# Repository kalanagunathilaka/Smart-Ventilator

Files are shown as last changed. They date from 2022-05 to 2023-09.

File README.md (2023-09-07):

# Smart Ventilator

This project aims to develop a low cost smart ventilator system that requires minimum professional interaction to operate using Atmega32 Microcontroller

**Objectives**

- To detect patient’s blood oxygen levels using the blood oxygen sensor (MAX30102)  and to provide oxygen where necessary.
- To monitor the patient’s vitals using the temperature sensor, pressure sensor, heart rate sensor and LCD display and send an alert message to a medical personnel using the gsm module or sound the speaker when it is necessary.
- To monitor a patient's blood oxygen level and automatically switch off oxygen supply when not needed.
- To be able to manually control all parameters of the air and oxygen flow supplied to the patient.

**System Block Diagram**

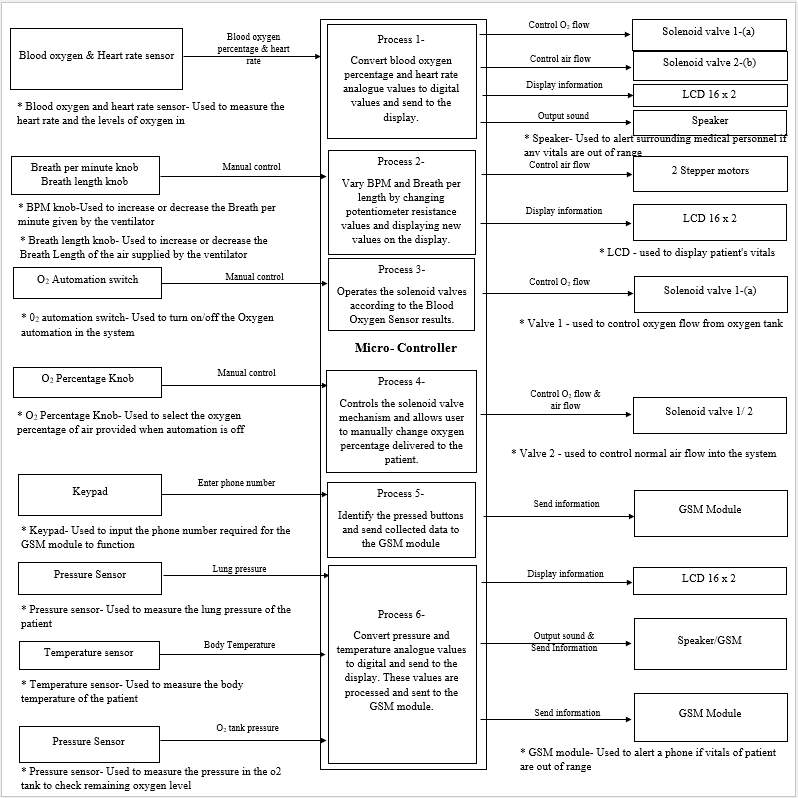
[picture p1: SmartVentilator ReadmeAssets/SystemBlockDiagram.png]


**Schematic of the product**

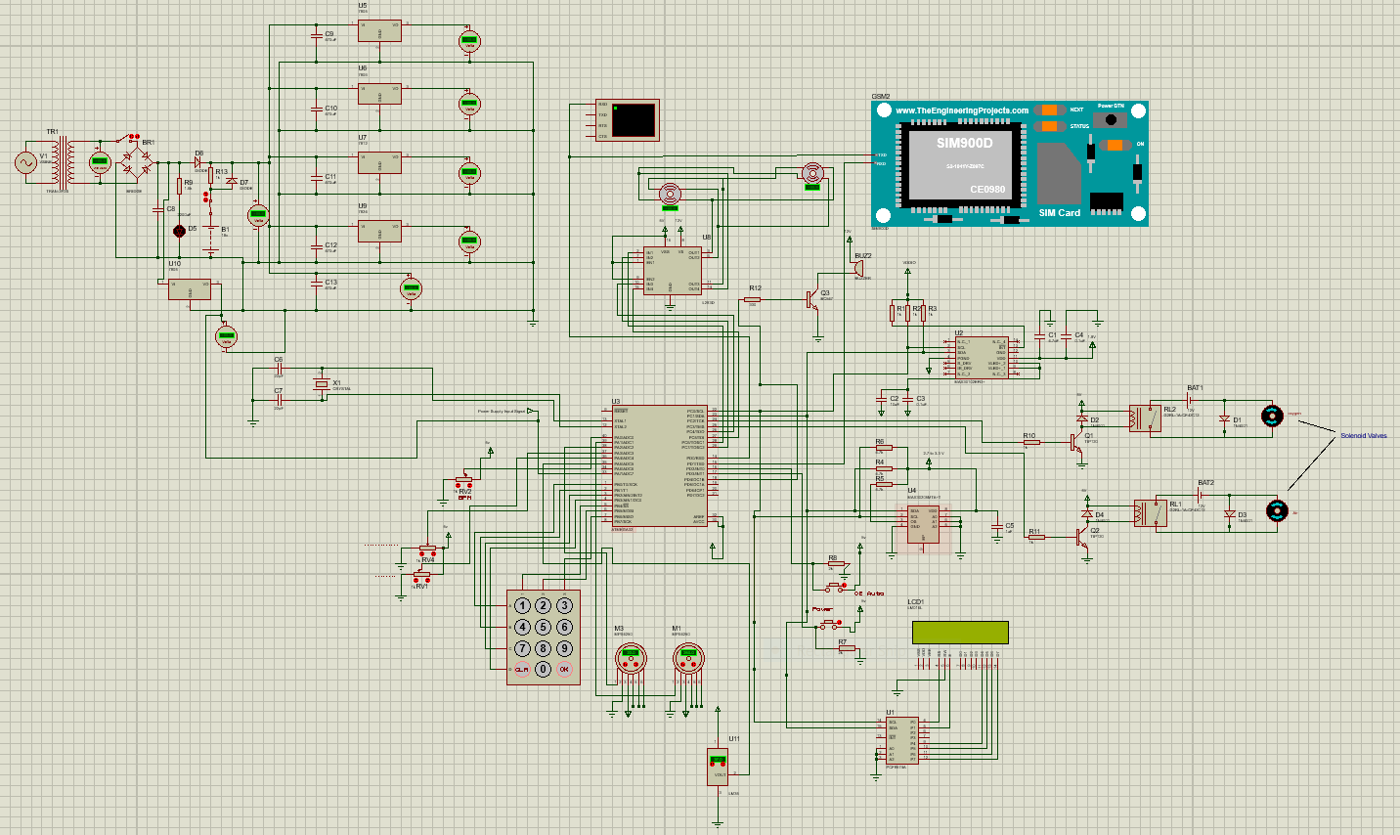
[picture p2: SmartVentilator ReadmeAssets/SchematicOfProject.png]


**3D Design of the System**

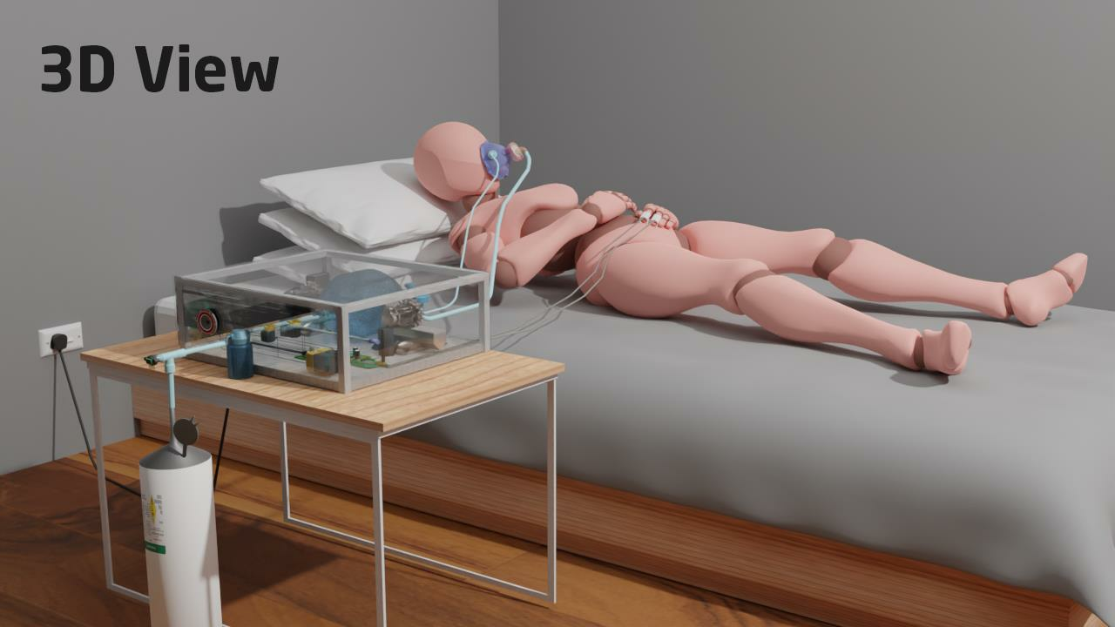
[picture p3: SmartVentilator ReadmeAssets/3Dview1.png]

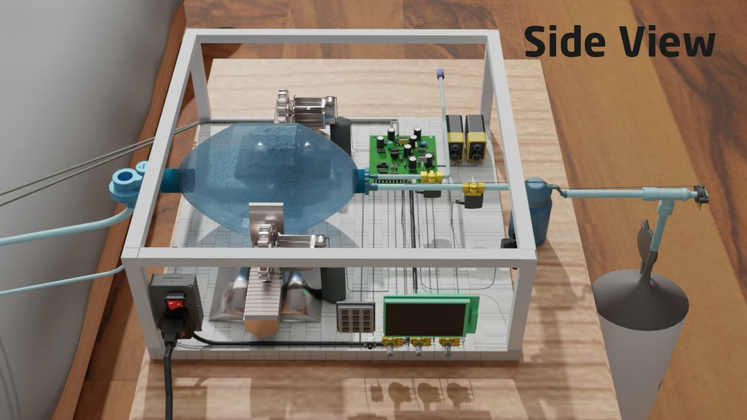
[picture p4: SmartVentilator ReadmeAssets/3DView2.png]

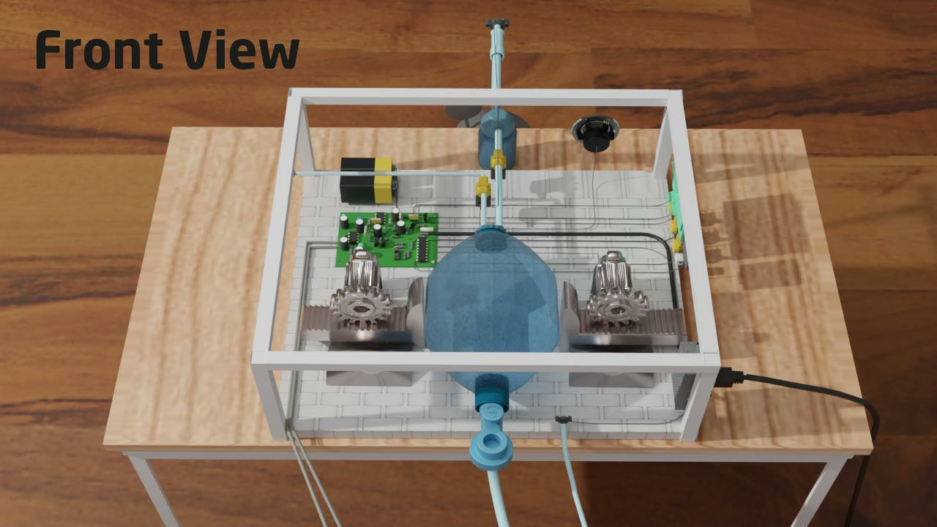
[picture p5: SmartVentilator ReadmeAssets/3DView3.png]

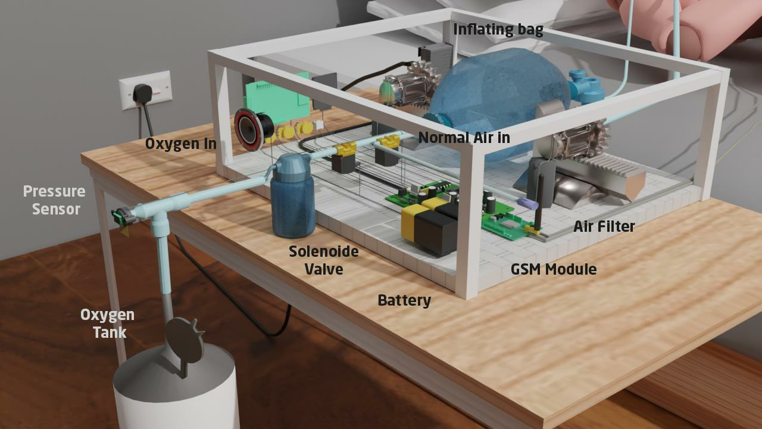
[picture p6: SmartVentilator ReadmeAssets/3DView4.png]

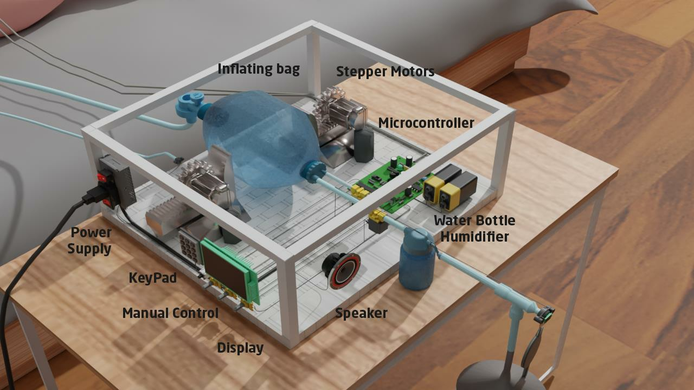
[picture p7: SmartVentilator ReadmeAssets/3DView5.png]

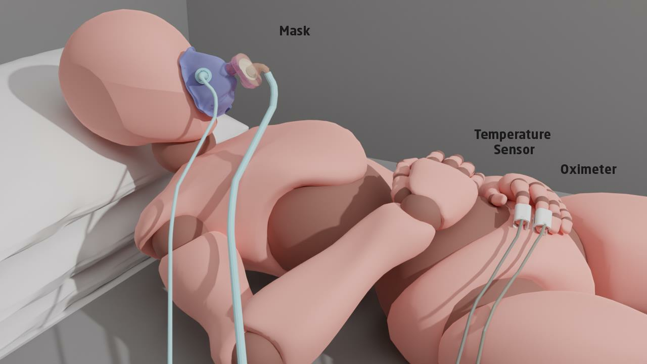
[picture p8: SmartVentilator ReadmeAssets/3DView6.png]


**PCB & 3D View of the Main Board**

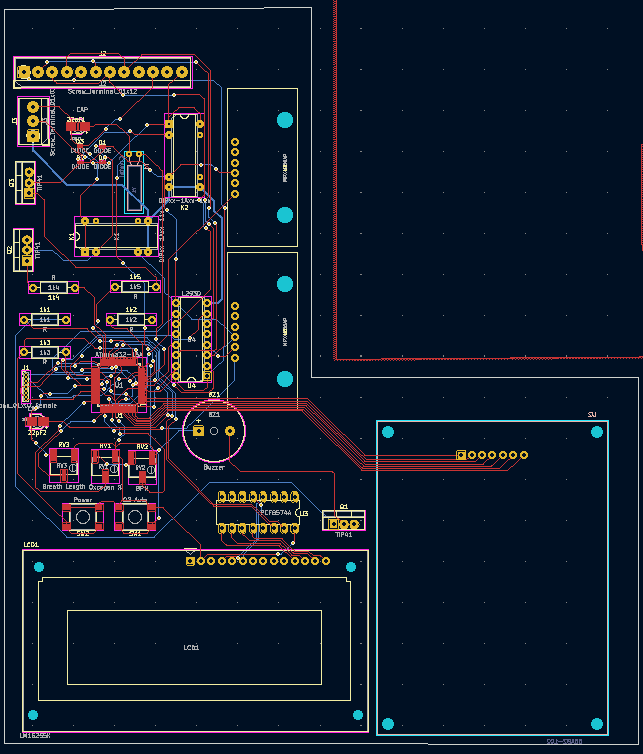
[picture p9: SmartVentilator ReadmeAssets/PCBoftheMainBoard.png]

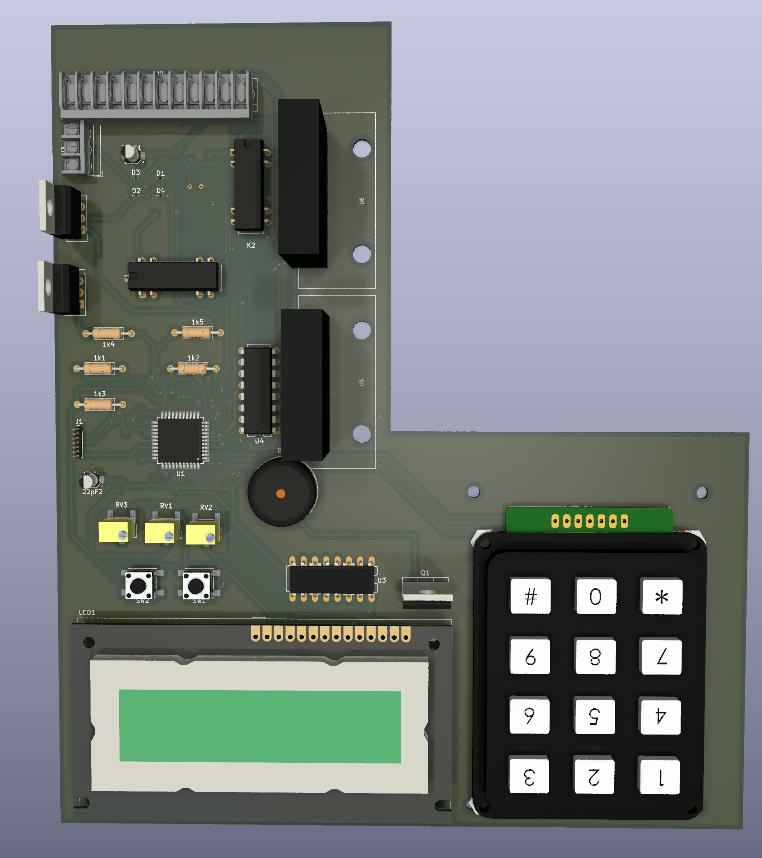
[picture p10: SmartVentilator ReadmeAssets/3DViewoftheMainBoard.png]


**PCB & 3D View of the Heart Rate & SPO2**

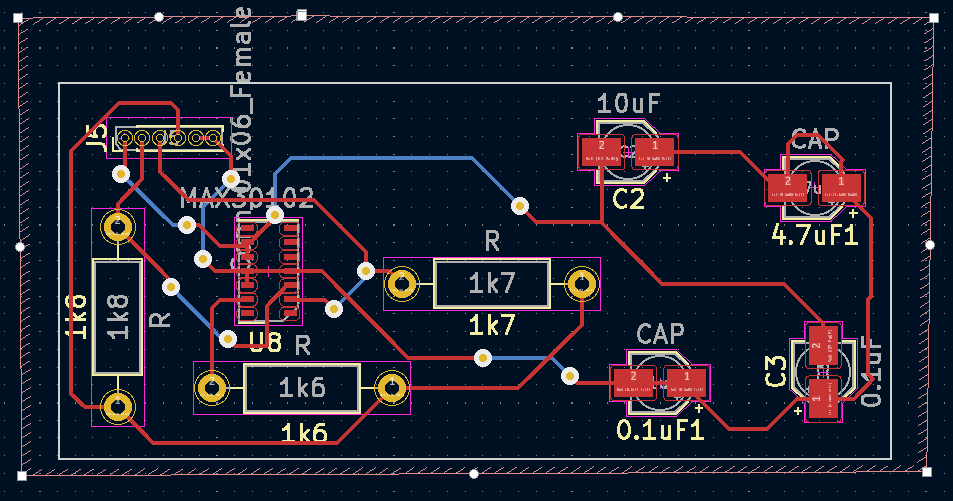
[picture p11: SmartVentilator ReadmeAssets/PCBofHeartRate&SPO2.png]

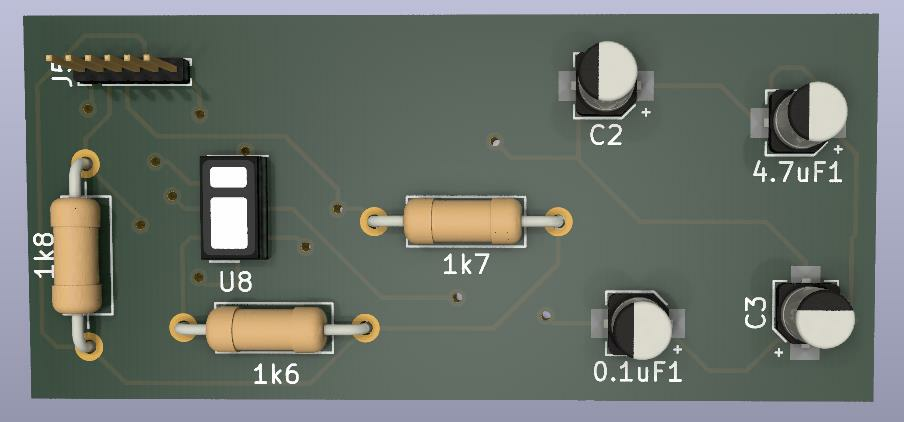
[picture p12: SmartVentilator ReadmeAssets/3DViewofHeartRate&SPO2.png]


**PCB & 3D View of Body Temperature Sensor**

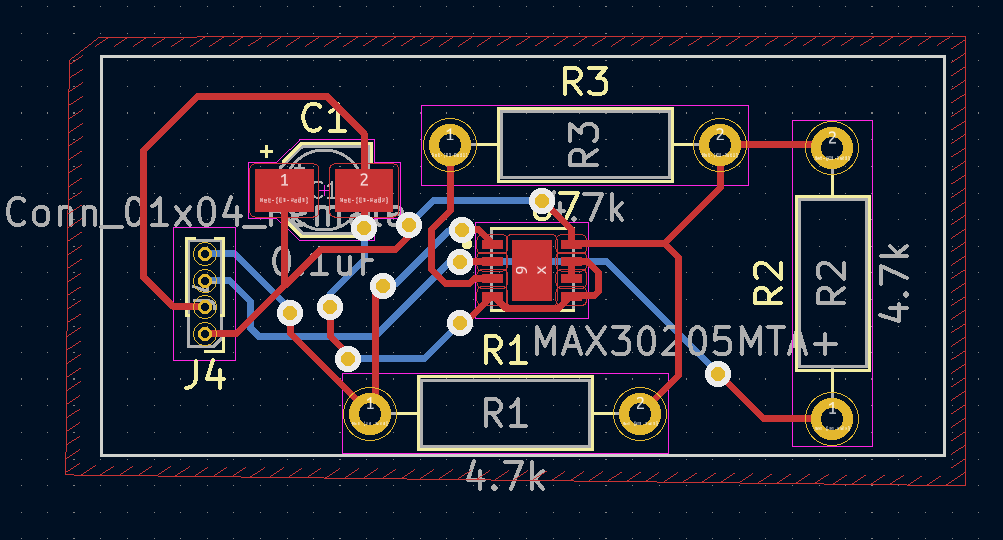
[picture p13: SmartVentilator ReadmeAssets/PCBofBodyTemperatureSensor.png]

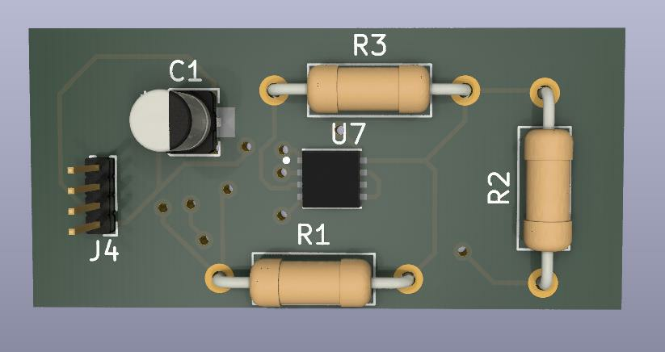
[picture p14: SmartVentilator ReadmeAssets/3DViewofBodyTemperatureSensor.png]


**PCB & 3D View of Power Supply**

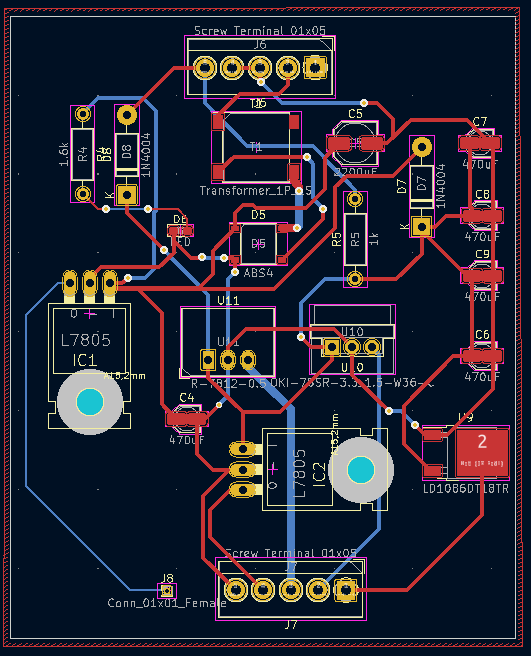
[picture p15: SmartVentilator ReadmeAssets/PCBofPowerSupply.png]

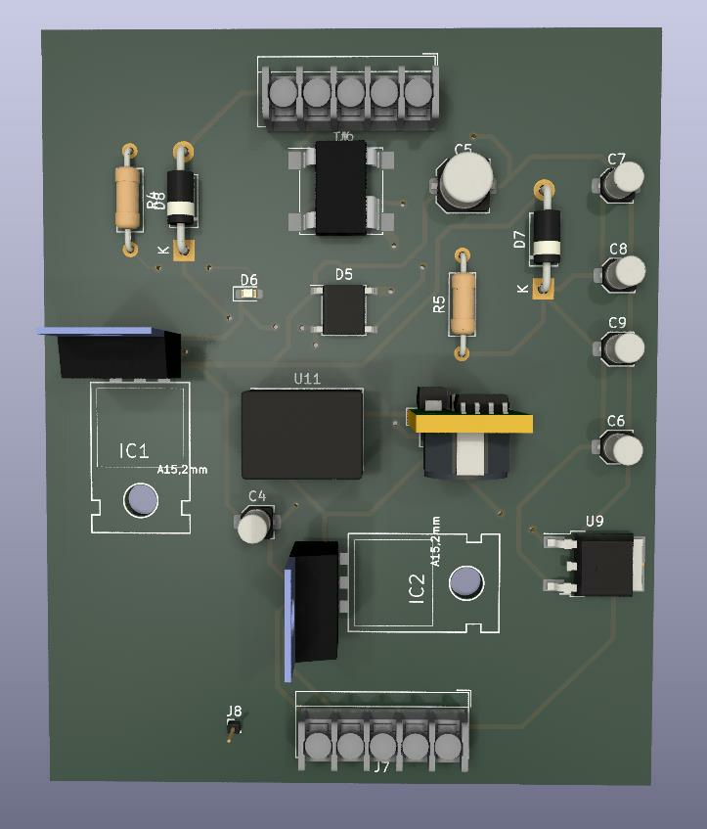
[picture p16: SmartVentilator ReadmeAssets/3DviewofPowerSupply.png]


[**3D Animation**](https://dms.uom.lk/s/HgEqCMnCMRMiKYt)

**Software Used**

- Microchip Studio - Program Microcontroller
- Proteus Design Suite - Design Schematic Diagram
- KiCad EDA - Design PCB
- Blender - Design 3D View
- Adobe After Effects & Premiere Pro - Design 3D Animation

**Contributors**

- [Yesitha Sathsara](https://github.com/yesitha)
- [Shakila Kularathna](https://github.com/shakila2030)
- [Nelaka Gunawardhana](https://github.com/NelakaGunawardhana)
- [Kalana Gunathilaka](https://github.com/KalanaLakshan)
- [Piyumanthi Nisansala](https://github.com/Piyumanthi)

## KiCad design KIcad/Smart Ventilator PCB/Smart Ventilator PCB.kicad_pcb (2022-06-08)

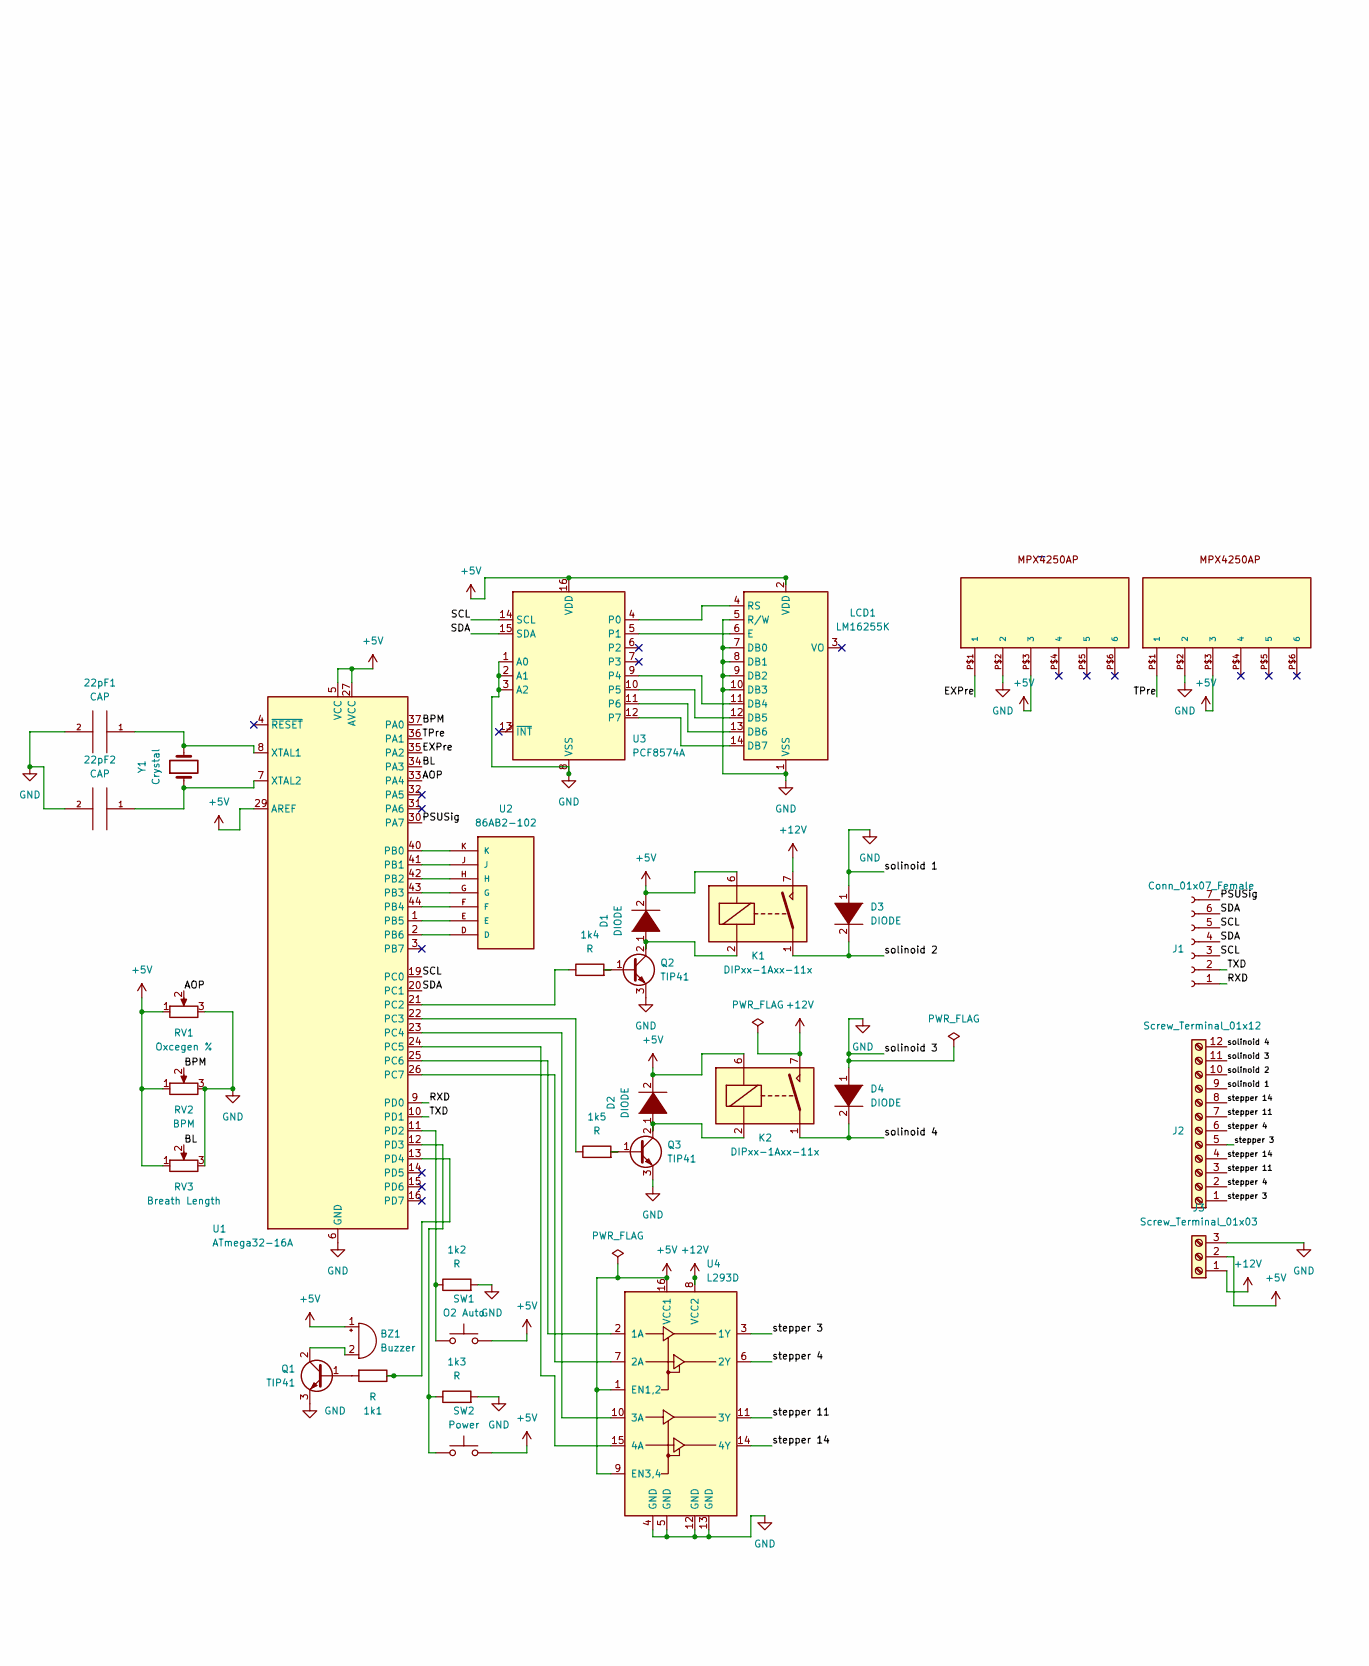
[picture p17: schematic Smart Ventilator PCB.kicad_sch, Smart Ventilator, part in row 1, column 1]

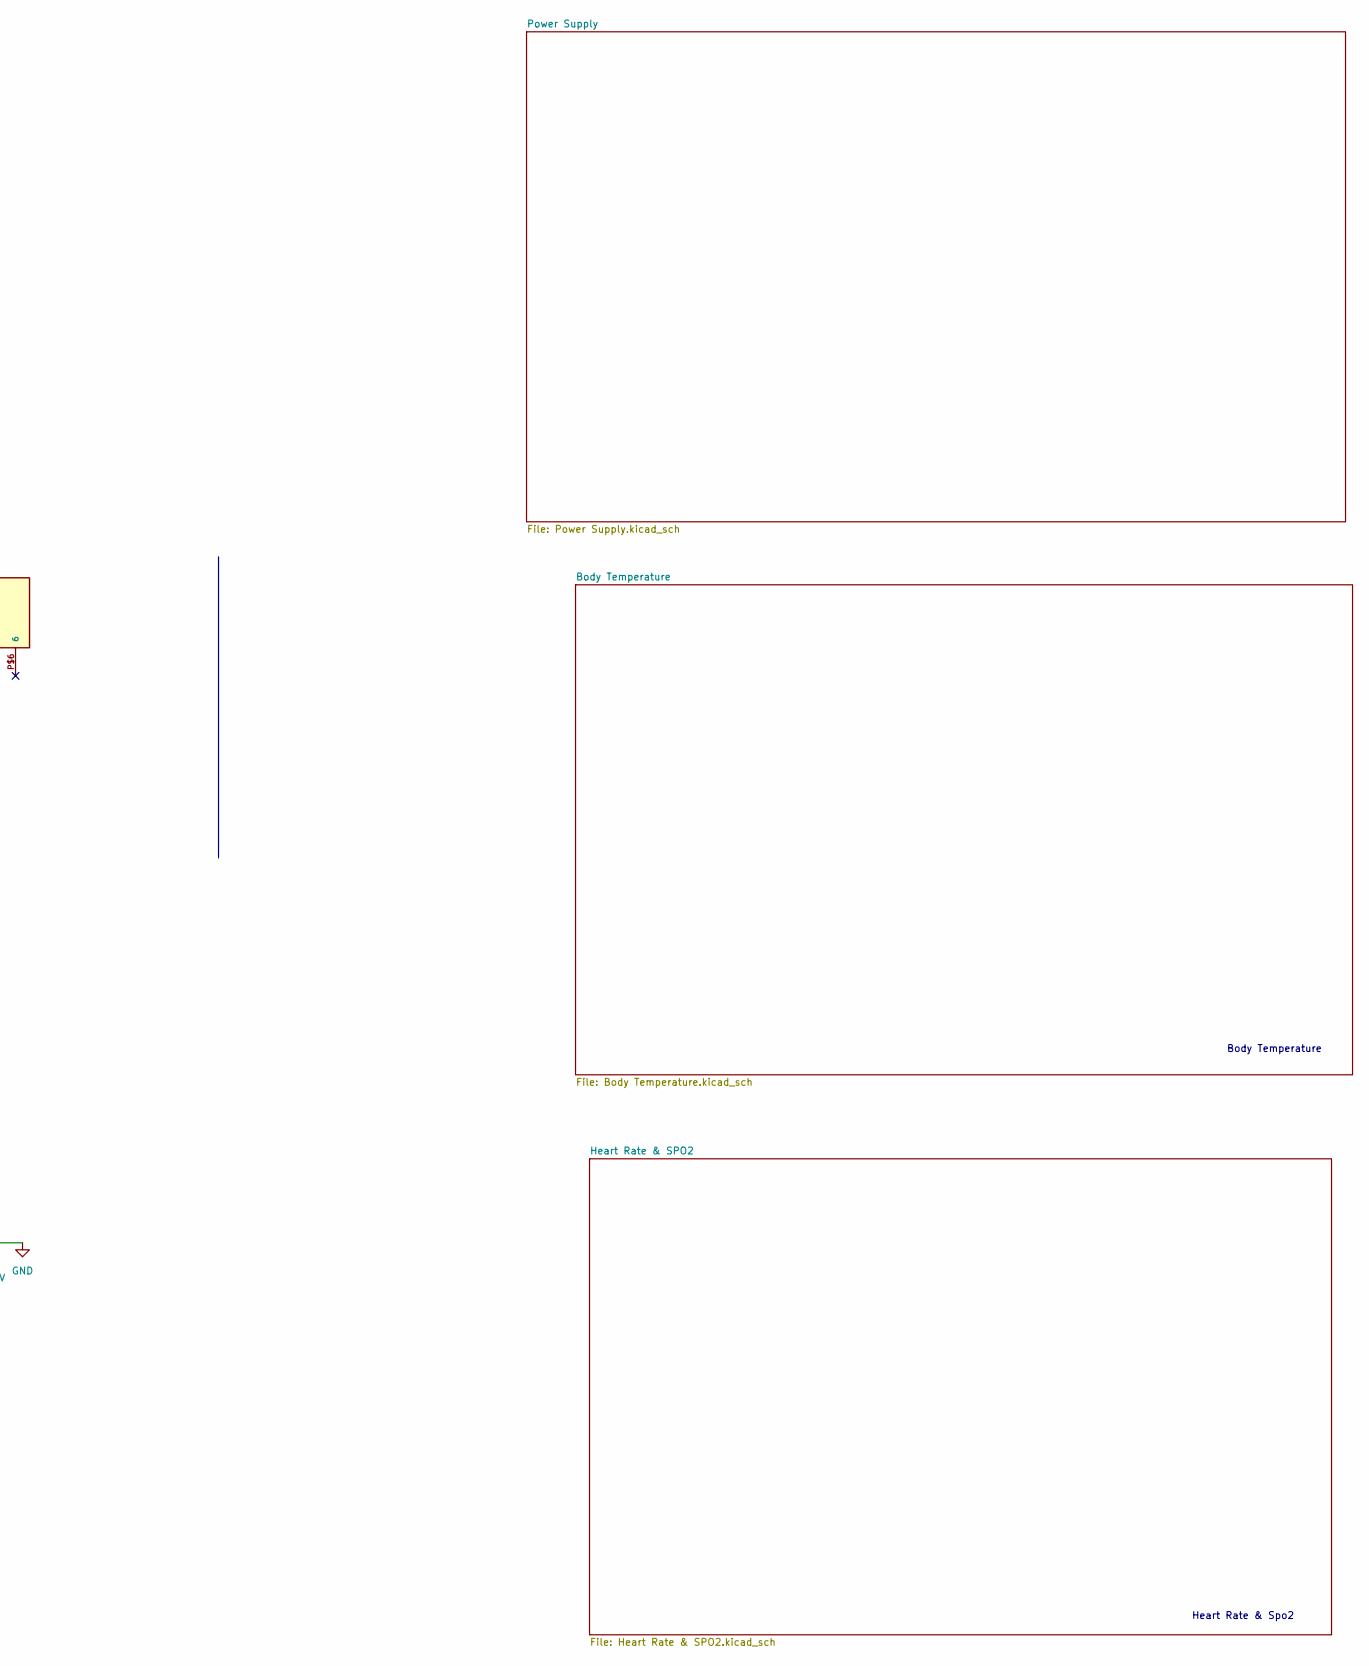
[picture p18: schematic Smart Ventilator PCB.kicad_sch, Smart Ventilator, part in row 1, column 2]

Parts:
1k1, 1k2, 1k3, 1k4, 1k5: R; R_Axial_DIN0207_L6.3mm_D2.5mm_P10.16mm_Horizontal
22pF1, 22pF2: CAP; CP_Elec_3x5.3
BZ1: Buzzer; Buzzer_15x7.5RM7.6
D1, D2, D3, D4: DIODE; D_0201_0603Metric
J1: Conn_01x07_Female; PinHeader_1x07_P1.00mm_Vertical
J2: Screw_Terminal_01x12; TerminalBlock_4Ucon_1x12_P3.50mm_Horizontal
J3: Screw_Terminal_01x03; TerminalBlock_4Ucon_1x03_P3.50mm_Horizontal
K1, K2: DIPxx-1Axx-11x; Relay_StandexMeder_DIP_LowProfile
LCD1: LM16255K; LM16255
Q1, Q2, Q3: TIP41; TO-220-3_Vertical
RV1: Oxcegen %; Potentiometer_Bourns_3269W_Vertical
RV2: BPM; Potentiometer_Bourns_3269W_Vertical
RV3: Breath Length; Potentiometer_Bourns_3269W_Vertical
SW1: O2 Auto; SW_Push_1P1T_NO_6x6mm_H9.5mm
SW2: Power; SW_Push_1P1T_NO_6x6mm_H9.5mm
U1: ATmega32-16A; TQFP-44_10x10mm_P0.8mm
U2: 86AB2-102; KEYPAD_86AB2-102
U3: PCF8574A; DIL16
U4: L293D; DIP-16_W7.62mm
U5, U6: MPX4250AP
Y1: Crystal; Crystal_AT310_D3.0mm_L10.0mm_Horizontal

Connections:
+5V: BZ1.1 (-), D1.2 (A), D2.2 (A), J3.2, K1.6, K2.6, LCD1.2 (VDD), RV1.1, RV2.1, RV3.1, SW1.2, SW2.2, U1.5 (VCC), U1.17 (VCC), U1.27 (AVCC), U1.29 (AREF), U1.38 (VCC), U3.16 (VDD), U4.1 (EN1,2), U4.9 (EN3,4), U4.16 (VCC1), U5.P$3 (3), U6.P$3 (3)
+12V: J3.1, K1.7, K1.8, K2.7, K2.8, U4.8 (VCC2)
/AOP: RV1.2, U1.33 (PA4)
/BL: RV3.2, U1.34 (PA3)
/BPM: RV2.2, U1.37 (PA0)
/EXPre: U1.35 (PA2), U5.P$1 (1)
/PSUSig: J1.7, U1.30 (PA7)
/RXD: J1.1, U1.9 (PD0)
/SCL: J1.3, J1.5, U1.19 (PC0), U3.14 (SCL)
/SDA: J1.4, J1.6, U1.20 (PC1), U3.15 (SDA)
/TPre: U1.36 (PA1), U6.P$1 (1)
/TXD: J1.2, U1.10 (PD1)
/solinoid 2: D3.2 (A), J2.10, K1.1, K1.14
/solinoid 4: D4.2 (A), J2.12, K2.1, K2.14
/stepper 3: J2.1, J2.5, U4.3 (1Y)
/stepper 4: J2.2, J2.6, U4.6 (2Y)
/stepper 11: J2.3, J2.7, U4.11 (3Y)
/stepper 14: J2.4, J2.8, U4.14 (4Y)
GND: 1k2.2, 1k3.2, 22pF1.2, 22pF2.2, D3.1 (K), D4.1 (K), J2.9, J2.11, J3.3, K2.9, K2.13, LCD1.1 (VSS), LCD1.5 (R/W), LCD1.7 (DB0), LCD1.8 (DB1), LCD1.9 (DB2), LCD1.10 (DB3), Q1.3 (E), Q2.3 (E), Q3.3 (E), RV1.3, RV2.3, RV3.3, U1.6 (GND), U1.18 (GND), U1.28 (GND), U1.39 (GND), U3.1 (A0), U3.2 (A1), U3.3 (A2), U3.8 (VSS), U4.4 (GND), U4.5 (GND), U4.12 (GND), U4.13 (GND), U5.P$2 (2), U6.P$2 (2)
unnamed: 1k1.1, U1.13 (PD4)
unnamed: 1k1.2, Q1.1 (B)
unnamed: 1k2.1, SW1.1, U1.11 (PD2)
unnamed: 1k3.1, SW2.1, U1.12 (PD3)
unnamed: 1k4.1, U1.21 (PC2)
unnamed: 1k4.2, Q2.1 (B)
unnamed: 1k5.1, U1.22 (PC3)
unnamed: 1k5.2, Q3.1 (B)
unnamed: 22pF1.1, U1.8 (XTAL1), Y1.2
unnamed: 22pF2.1, U1.7 (XTAL2), Y1.1
unnamed: BZ1.2 (+), Q1.2 (C)
unnamed: D1.1 (K), K1.2, Q2.2 (C)
unnamed: D2.1 (K), K2.2, Q3.2 (C)
unnamed: LCD1.4 (RS), U3.4 (P0)
unnamed: LCD1.6 (E), U3.5 (P1)
unnamed: LCD1.11 (DB4), U3.9 (P4)
unnamed: LCD1.12 (DB5), U3.10 (P5)
unnamed: LCD1.13 (DB6), U3.11 (P6)
unnamed: LCD1.14 (DB7), U3.12 (P7)
unnamed: U1.1 (PB5), U2.E
unnamed: U1.2 (PB6), U2.D
unnamed: U1.23 (PC4), U4.10 (3A)
unnamed: U1.24 (PC5), U4.15 (4A)
unnamed: U1.25 (PC6), U4.2 (1A)
unnamed: U1.26 (PC7), U4.7 (2A)
unnamed: U1.40 (PB0), U2.K
unnamed: U1.41 (PB1), U2.J
unnamed: U1.42 (PB2), U2.H
unnamed: U1.43 (PB3), U2.G
unnamed: U1.44 (PB4), U2.F

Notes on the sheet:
Body Temperature
Heart Rate & Spo2

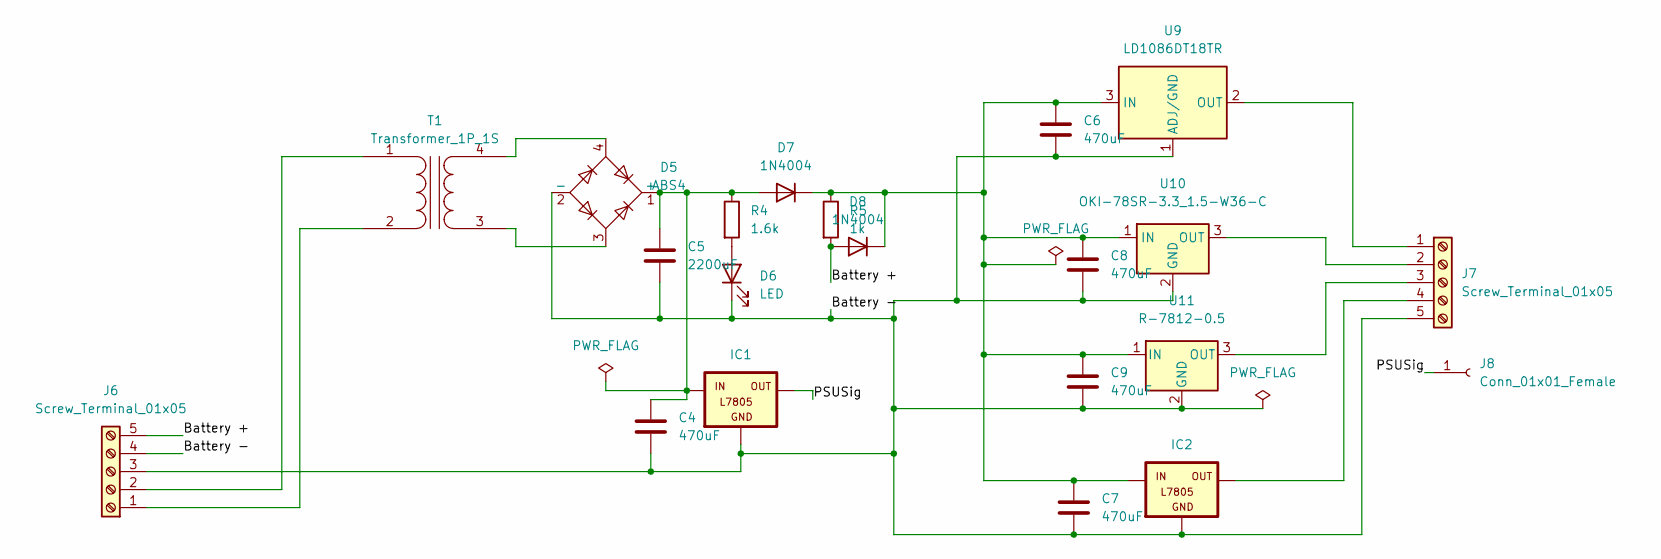
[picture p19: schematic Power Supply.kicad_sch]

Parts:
C4, C6, C7, C8, C9: 470uF; C_Elec_3x5.4
C5: 2200uF; C_Elec_5x5.4
D5: ABS4; Diode_Bridge_Diotec_ABS
D6: LED; LED_0603_1608Metric_Pad1.05x0.95mm_HandSolder
D7, D8: 1N4004; D_DO-41_SOD81_P10.16mm_Horizontal
IC1, IC2: L7805; 78XXL
J6, J7: Screw_Terminal_01x05; TerminalBlock_4Ucon_1x05_P3.50mm_Horizontal
J8: Conn_01x01_Female; PinHeader_1x01_P1.00mm_Vertical
R4: 1.6k; R_Axial_DIN0207_L6.3mm_D2.5mm_P10.16mm_Horizontal
R5: 1k; R_Axial_DIN0207_L6.3mm_D2.5mm_P10.16mm_Horizontal
T1: Transformer_1P_1S; Transformer_Toroid_Horizontal_D9.0mm_Amidon-T30
U9: LD1086DT18TR; TO-252-2
U10: OKI-78SR-3.3_1.5-W36-C; Converter_DCDC_Murata_OKI-78SR_Vertical
U11: R-7812-0.5; Converter_DCDC_RECOM_R-78E-0.5_THT

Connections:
/Power Supply/Battery +: D8.2 (A), J6.5, R5.2
/Power Supply/Battery -: C4.2, C5.2, C6.2, C7.2, C8.2, C9.2, D5.2 (-), D6.1 (K), IC1.GND, IC2.GND, J6.3, J6.4, J7.5, U9.1 (ADJ/GND), U10.2 (GND), U11.2 (GND)
/Power Supply/PSUSig: IC1.OUT, J8.1
unnamed: C4.1, C5.1, D5.1 (+), D7.2 (A), IC1.IN, R4.1
unnamed: C6.1, C7.1, C8.1, C9.1, D7.1 (K), D8.1 (K), IC2.IN, R5.1, U9.3 (IN), U10.1 (IN), U11.1 (IN)
unnamed: D5.3, T1.3 (SA)
unnamed: D5.4, T1.4 (SB)
unnamed: D6.2 (A), R4.2
unnamed: IC2.OUT, J7.4
unnamed: J6.1, T1.2 (AB)
unnamed: J6.2, T1.1 (AA)
unnamed: J7.1, U9.2 (OUT)
unnamed: J7.2, U10.3 (OUT)
unnamed: J7.3, U11.3 (OUT)

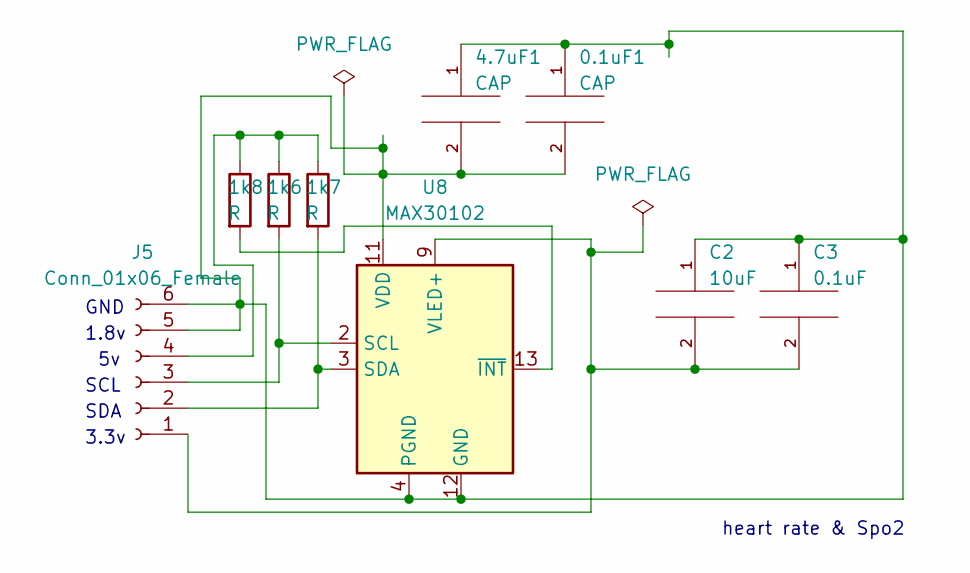
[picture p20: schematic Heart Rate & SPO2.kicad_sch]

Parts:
0.1uF1, 4.7uF1: CAP; CP_Elec_3x5.3
1k6, 1k7, 1k8: R; R_Axial_DIN0207_L6.3mm_D2.5mm_P10.16mm_Horizontal
C2: 10uF; CP_Elec_3x5.3
C3: 0.1uF; CP_Elec_3x5.3
J5: Conn_01x06_Female; PinHeader_1x06_P1.00mm_Vertical
U8: MAX30102; Maxim_OLGA-14_3.3x5.6mm_P0.8mm

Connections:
unnamed: 0.1uF1.1, 0.1uF1.2, 4.7uF1.1, 4.7uF1.2, C2.1, C3.1, J5.5, J5.6, U8.4 (PGND), U8.11 (VDD), U8.12 (GND)
unnamed: 1k6.1, 1k7.1, 1k8.1, J5.4
unnamed: 1k6.2, U8.13 (~INT)
unnamed: 1k7.2, J5.3, U8.2 (SCL)
unnamed: 1k8.2, J5.2, U8.3 (SDA)
unnamed: C2.2, C3.2, J5.1, U8.9 (VLED+), U8.10 (VLED+)

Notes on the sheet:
heart rate & Spo2
GND
SDA
1.8v
SCL
3.3v

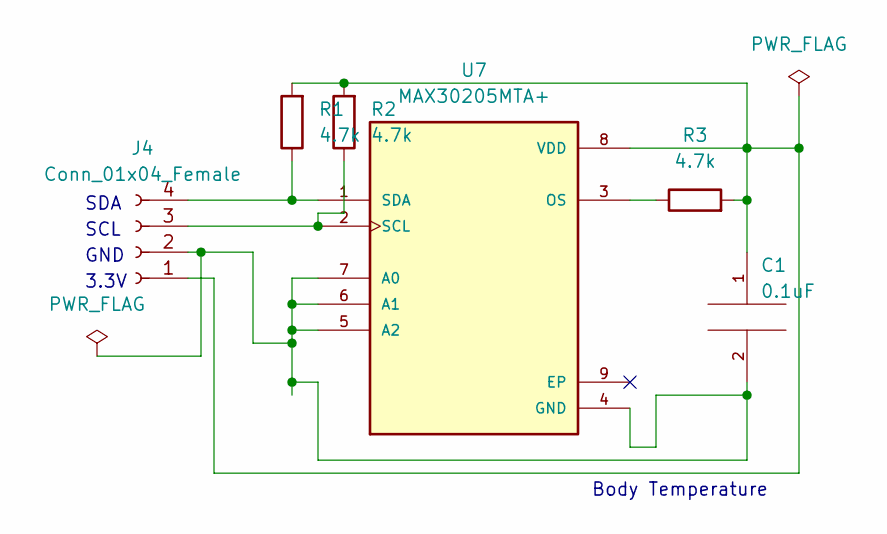
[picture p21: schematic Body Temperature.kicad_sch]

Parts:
C1: 0.1uF; CP_Elec_3x5.3
J4: Conn_01x04_Female; PinHeader_1x04_P1.00mm_Vertical
R1, R2, R3: 4.7k; R_Axial_DIN0207_L6.3mm_D2.5mm_P10.16mm_Horizontal
U7: MAX30205MTA+; SON65P300X300X80-9N

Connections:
unnamed: C1.1, J4.1, R1.2, R2.2, R3.2, U7.8 (VDD)
unnamed: C1.2, J4.2, U7.4 (GND), U7.5 (A2), U7.6 (A1), U7.7 (A0)
unnamed: J4.3, R2.1, U7.2 (SCL)
unnamed: J4.4, R1.1, U7.1 (SDA)
unnamed: R3.1, U7.3 (OS)

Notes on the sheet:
3.3V
SDA
SCL
Body Temperature
GND

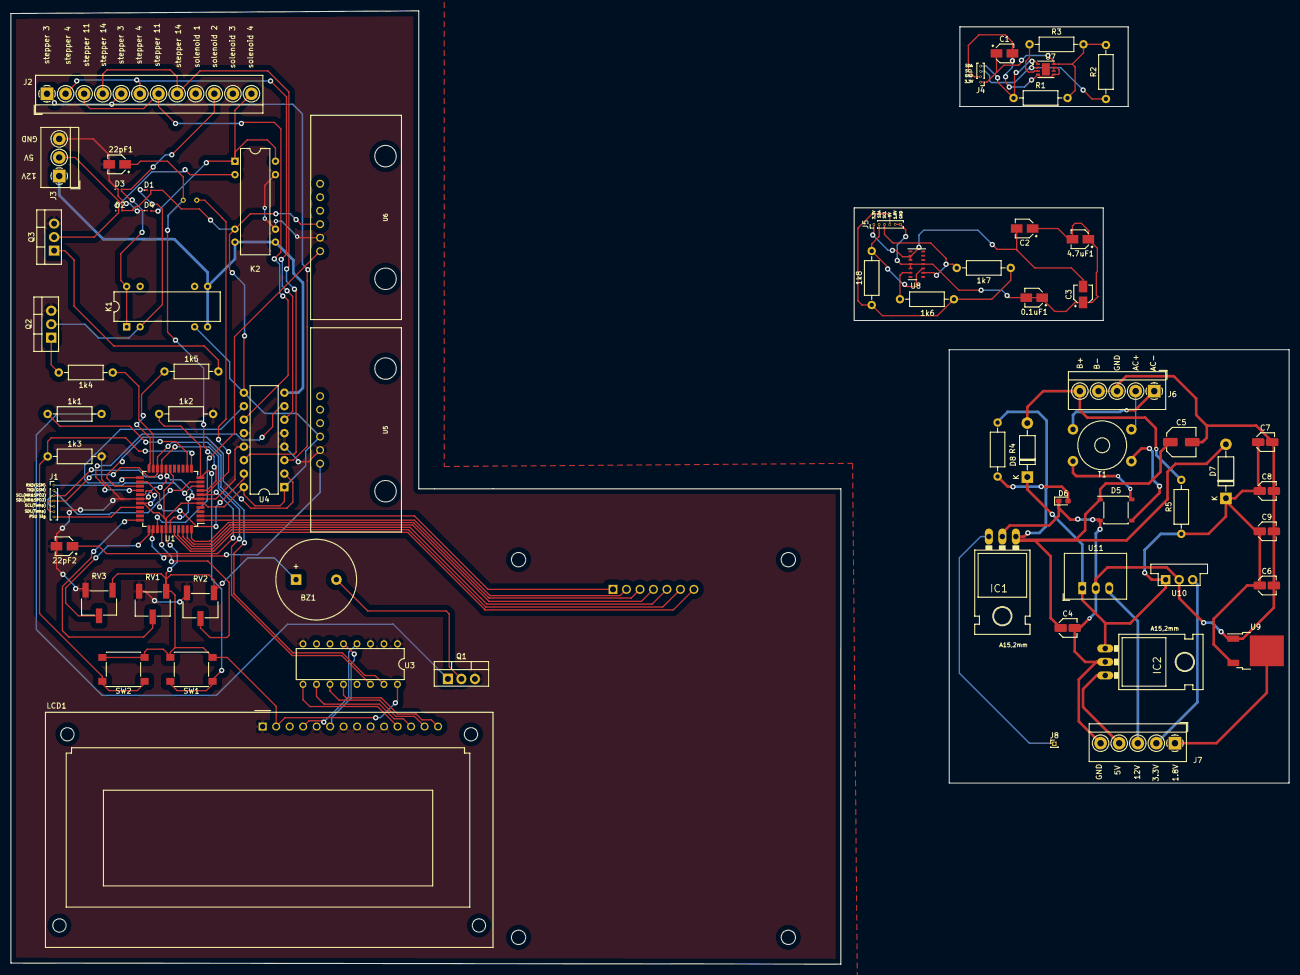
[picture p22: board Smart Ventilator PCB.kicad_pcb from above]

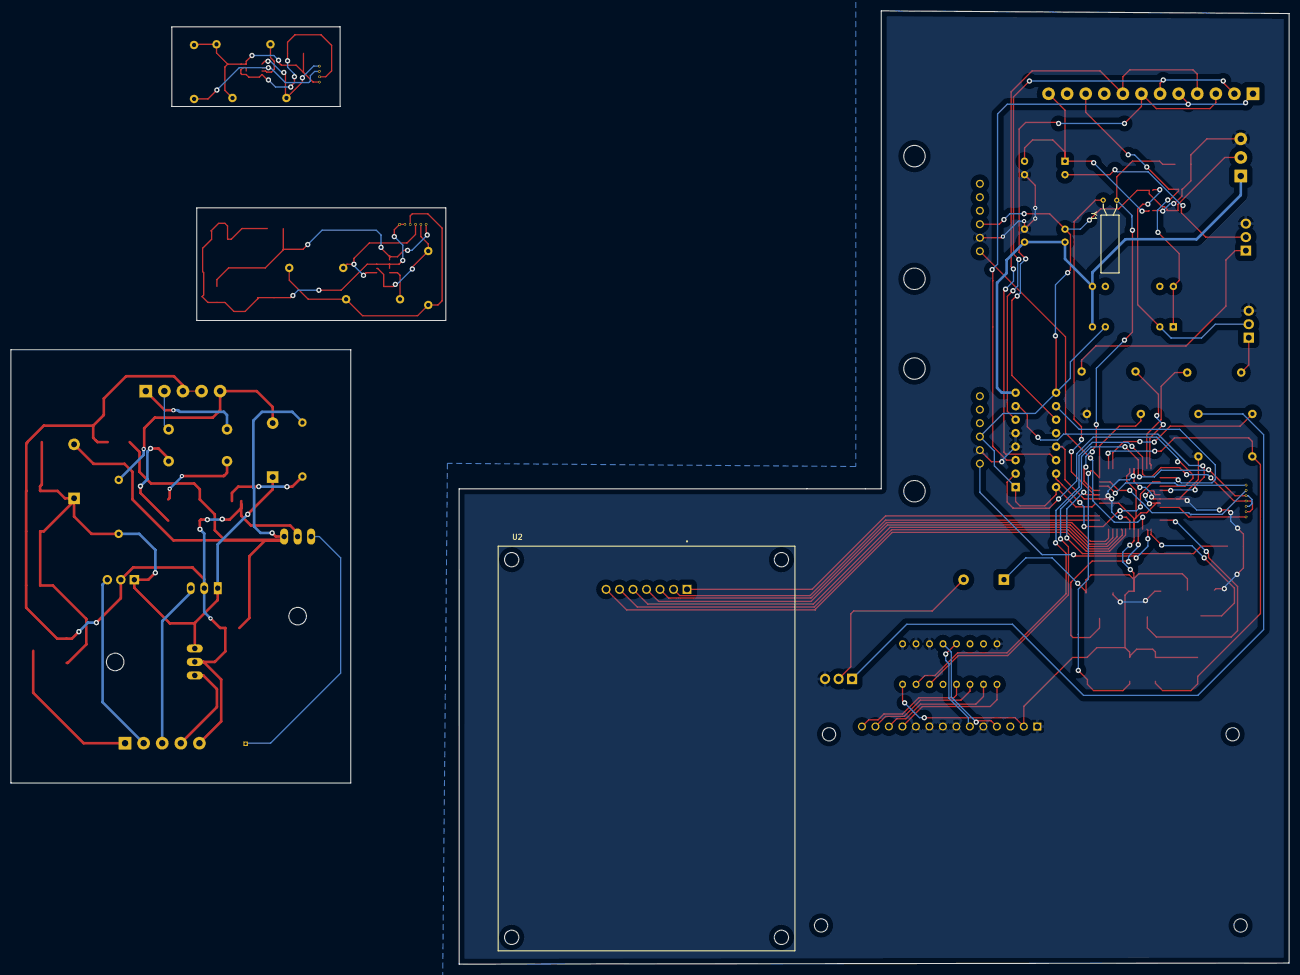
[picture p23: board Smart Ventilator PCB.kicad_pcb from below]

Board: 2 copper layers, 240.7 x 179.5 mm, 69 parts (2 on the bottom side), 74 nets.

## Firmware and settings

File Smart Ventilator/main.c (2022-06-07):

/*
 * Smart Ventilator.c
 *
 * Created: 11/27/2021 1:26:16 PM
 * Author : Yesitha Sathsara
 */
#define F_CPU 8000000UL
#include <avr/io.h>
#include <stdbool.h>
#include <math.h>
#include <util/delay.h>
#include <stdio.h>
#include <string.h>
#include <stdlib.h>
#include <millis.h>
#include <avr/interrupt.h>
#include "lcd.h"
#include "i2c.h"
#include "keypad.h"
#include "string.h"
#include "GSM.h"
#include "solenoidValves.h"
#include "stepper motor.h"
#include "potentiometer.h"
#include "MPX4250 Pressure Sensor.h"
#include "LM35 Temperature Sensor.h"

bool checkStatus();
int oxygenTankPercentage();
void notifyGSM(const char *string, int percentage);
void notifyDisplay(const char *string);
void delay_ms(double ms);
bool automationOn();
void getParametersFromKnobs();
bool checkPatientTemp();
int PatientTemp();
int checkBloodOxygenLevel();
void startAirSupply();
void controlOxygenPercentage(int bloodOxygenLevel);
void notifySpeaker();
bool turnOn();
void startStepperMotor(int breathPerMin, int BreathLength);
void startOxygenAndAirSupply(int percentage);
void controlSolenoidValve(double oxygenPercentage, int breathPerMin);
void rotateFullBackward(int breathPerMin);
void rotateFullForward(int breathPerMin);
double getOxygenTankPressure();
void openSolenoidValves(double air, double oxygen);
void GSMConnect();
void sendSMS(char no[11], const char *string);
bool checkPower();
int checkPatientExpPresure();

const char *concatS(const char *string, char sPercentage[4]);
char *boolstring(_Bool b);
int Average_Blood_Oxygen_level = 94;
int Average_Breath_length = 50;
int Average_Breath_Per_Min = 12;
int Oxygen_percentage = 90;
char Mobile_no[11];

unsigned char x;
bool power = true;
bool OxygenAutomation = true;
int Set_Heart_Rate();

int rBPM;
int rHR;
int rBL;
int rOP;
int i;
int caseADC = 1;
char String[5];
int value;
int powerfailure;
unsigned long case_num2;
unsigned long prev_millis2;
unsigned long need_millis2;

int main(void)
{

    DDRC = DDRC | (1 << 2); // solenoid valve
    DDRC = DDRC | (1 << 3); // solenoid valve
    DDRC = DDRC | (1 << 4); // stepper motor
    DDRC = DDRC | (1 << 5); // stepper motor
    DDRC = DDRC | (1 << 6); // stepper motor
    DDRC = DDRC | (1 << 7); // stepper motor

    DDRB = 0x0F;            // 0,1,3,2--->1   4,5,6,7-->0 for keypad
    DDRD = DDRD | (0 << 2); // PD2 as Oxygen Automation
    DDRD = DDRD | (0 << 3); // PD3 as input for power on
    DDRD = DDRD | (1 << 4); // Speaker
    DDRA = DDRA | (0 << 7); // PA7 as input for power supply

    MCUCR |= 1 << ISC01; // interrupt fire on falling edge in INT0
    MCUCR |= 1 << ISC11; // interrupt fire on falling edge in INT1

    //
    GICR |= 1 << INT0; // Enable the external interrupt source in general interrupt control register
    GICR |= 1 << INT1; // Enable the external interrupt source in general interrupt control register
	
    init_millis(8000000UL);
    sei();
    ADC_Init();
    i2c_init();
    i2c_start();
    i2c_write(0x70);
    lcd_init();
	
	
    lcd_cmd(0x80);
    lcd_msg("Enter Phone");
    _delay_ms(30);
    lcd_cmd(0xC0);
    _delay_ms(10);
    lcd_msg("Number");
    _delay_ms(30);
    lcd_cmd(0x01);
    _delay_ms(100);
    lcd_cmd(0x80);

initialPoint:
    lcd_cmd(0x01);

    PORTB = 0xF0;
    int f = 0;
    do
    {
        x = Keypad();
        Mobile_no[f]=x;
         
        if (((PINB & (1 << PINB4)) == 0) || ((PINB & (1 << PINB5)) == 0) || ((PINB & (1 << PINB6)) == 0))
        {
            f++;
        }
        lcd_msg(x);
        _delay_ms(70);

        if ((PINB & (1 << PINB4)) == 0) // clr button
        {
            goto initialPoint;
        }
        if ((PINB & (1 << PINB6)) == 0) // ok button
        {
            break;
        }

    } while (PINB != 0xF0);
   
    lcd_cmd(0x01);
	lcd_cmd(0x80);
    lcd_msg("Number");
    lcd_cmd(0xc0);
    lcd_msg("Registered");
    _delay_ms(100);
    lcd_cmd(0x01);
	

    USART_Init(9600);
    _delay_ms(1000);
    GSMConnect();
    

    while (1)
    {
		switch (caseADC)
		{
			case 1:
			{
				ADC_Init();
				value = ADC_Read(3);
				rBL = ((value * 500) / 1024) + 250; // BL range vary from 250 to 750
				caseADC++;
				break;
				
			}
			case 2:
			{
				ADC_Init();
				value = ADC_Read(0);
				rBPM = ((value * 14) / 1024) + 10; // BPM range vary from 10 to 24
				caseADC=1;
				break;
			}
			
		}
		
		if(prev_millis2==NULL){
			
			prev_millis2=millis();
			need_millis2=500+prev_millis2;
			case_num2=1;
			     char Spercentage[4];
			     lcd_cmd(0x01);
				 lcd_cmd(0x80);
				 itoa(checkBloodOxygenLevel(), Spercentage, 10);
				 lcd_msg(concatS("PBO2L-", Spercentage));
				 itoa(Set_Heart_Rate(), Spercentage, 10);
				 lcd_msg(concatS("  HR-", Spercentage));
				 lcd_cmd(0xc0);
				 itoa(PatientTemp(), Spercentage, 10);
				 lcd_msg(concatS("Temp-",Spercentage));
				 itoa(checkPatientExpPresure(), Spercentage, 10);
				 lcd_msg(concatS(" ExpP-", Spercentage));
			case_num2++;
			}else if(need_millis1<millis()){
			
			switch(case_num2){
				
				case 2:{
					lcd_cmd(0x01);
					lcd_cmd(0x80);
					char Spercentage1[4];
					itoa(rBPM, Spercentage1, 10);
					lcd_msg(concatS("BPM-", Spercentage1));
					itoa(rBL, Spercentage1, 10);
					lcd_msg(concatS("   BL-", Spercentage1));
					lcd_cmd(0xc0);
					itoa(oxygenTankPercentage(), Spercentage1, 10);
					lcd_msg(concatS("O2TP-", Spercentage1));
					itoa(Oxygen_percentage, Spercentage1, 10);
					lcd_msg(concatS(" AO2P-", Spercentage1));
					case_num2++;
					need_millis2=need_millis2+500;
					break;
				} 
				
				default:{case_num2=NULL;
					prev_millis2=NULL;
				}
			}
		}
		
		
		
		
		
		
		
       
       

        

        if (checkStatus())
        {
            if (automationOn())
            {
                if (checkPatientTemp())
                {

                    if (checkBloodOxygenLevel() < Average_Blood_Oxygen_level)
                    {
                        startOxygenAndAirSupply(Oxygen_percentage);
                    }
                    else
                    {
                        startAirSupply();
                    }
                }
            }
            else
            {
                checkPatientTemp();
                getParametersFromKnobs(); // update o2 percentage manually
                controlSolenoidValve(Oxygen_percentage, rBPM);
                startStepperMotor(rBPM, rBL);
            }
        }
        else
        {
            return 0;
        }
    }
}
ISR(INT0_vect)
{ // External interrupt

    OxygenAutomation = !OxygenAutomation;

    if (OxygenAutomation)
    {
        lcd_cmd(0x01);
        lcd_msg("O2 Auto On");
    }
    else
    {
        lcd_cmd(0x01);
        lcd_msg("O2 Auto Off");
    }
    _delay_ms(50);
    lcd_cmd(0x01);
}
ISR(INT1_vect)
{ // External interrupt
    power = !power;
    if (power)
    {
        lcd_cmd(0x01);
        lcd_msg("Power On");
    }
    else
    {
        lcd_cmd(0x01);
        lcd_msg("Power Off");
    }
    _delay_ms(50);
    lcd_cmd(0x01);
}

void startOxygenAndAirSupply(int percentage)
{
    controlOxygenPercentage(checkBloodOxygenLevel());
    controlSolenoidValve(Oxygen_percentage, rBPM);
    startStepperMotor(rBPM, rBL);
}
void controlOxygenPercentage(int bloodOxygenLevel)
{
    if (bloodOxygenLevel < 40)
    {
        Oxygen_percentage = 90;
    }
    else if (bloodOxygenLevel < 70)
    {
        Oxygen_percentage = 70;
    }
    else if (bloodOxygenLevel < 90)
    {
        Oxygen_percentage = 60;
    }
    else if (bloodOxygenLevel < 94)
    {
        Oxygen_percentage = 40;
    }
    // update variable Oxygen Percentage According to Blood Oxygen Level
}

void controlSolenoidValve(double oxygenPercentage, int breathPerMin)
{
    double inflationTime = 30.0000 / breathPerMin;
    double tAir;    // Air Solenoid Valve Time
    double tOxygen; // Oxygen Solenoid Valve Time
    double constValue;
    double Pressure = 101325;
    double airDensity = 1.225;
    double OxygenDensity = 1.355;

    constValue = (0.79 * (1.266 * oxygenPercentage - 26.67) / (100 - oxygenPercentage)) * sqrt(Pressure * OxygenDensity / getOxygenTankPressure() / airDensity);
    if (constValue > 1)
    {
        tOxygen = inflationTime;
        tAir = tOxygen / constValue;
        openSolenoidValves(tAir, tOxygen); // values in s
    }
    else
    {
        tAir = inflationTime;
        tOxygen = tAir * constValue;
        openSolenoidValves(tAir, tOxygen); // values in s
    }
}

double getOxygenTankPressure()
{
    float kilopascal = get_pressure(1); 
	return kilopascal*1000; // return Oxygen tank pressure in pascal
}

void startAirSupply()
{
    startStepperMotor(rBPM, rBL);
    controlSolenoidValve(0, rBPM);
}
int checkBloodOxygenLevel()
{

    return 39; // return Blood Oxygen Level
}

int PatientTemp()
{
	float temp;
	temp= get_Temperature();
    return temp; // return temperature value
}

void notifySpeaker()
{
    DDRD = DDRD | (1 << 4);
}

bool checkPatientTemp()
{
    if (PatientTemp() > 37.2 || PatientTemp() < 36.1)
    {
        notifyGSM("Temperature Not Normal-", PatientTemp());
        char Spercentage[4];
        itoa(PatientTemp(), Spercentage, 10); // convert int to string
        notifyDisplay(concatS("Abnormal Temp-", Spercentage));
        notifySpeaker();
        return 0;
    }
    else
    {
        return 1;
    }
    // if normal return 1 else notify speaker and gsm
}

void getParametersFromKnobs()
{
 
	 ADC_Init();
	 value = ADC_Read(4);
	 rOP = (100 * value) / 1024; // OP range vary from 0 to 100
	 Oxygen_percentage = rOP;
    // get values and update  Breath per min,Oxygen Percentage,Breath Length
}

bool automationOn()
{
    return OxygenAutomation; // Check Automation On/Off
}

bool turnOn()
{
    return power; // return 1 if power on switched pressed else return 0
}

bool checkStatus()
{
    if (turnOn())
    {
        if (oxygenTankPercentage() < 10)
        {
            notifyGSM("Oxygen Tank Percentage : ", oxygenTankPercentage());
            char Spercentage[4];
            itoa(oxygenTankPercentage(), Spercentage, 10); // convert int to string
            notifyDisplay(concatS("OxyTank % ", Spercentage));
        }
        if (!checkPower())
        {
            if (powerfailure == NULL)
            {
                lcd_msg("POWER FAILURE");
                lcd_cmd(0x01);
                powerfailure = 1;
            }
            notifySpeaker();
        }
        else
        {
            powerfailure = NULL;
            DDRD = DDRD | (0 << 4);
        }
        return 1;
    }
    else
    {
        return 0;
    }
}

void notifyDisplay(const char *string)
{
    lcd_msg(string);
    lcd_cmd(0x01);
}

bool checkPower()
{
    if ((PINA & (1 << PINA7)) == (1 << PINA7))
    {
        return 1; // pin is high
    }
    else
    {
        return 0; // pin is low
    }
}

void notifyGSM(const char *string, int percentage)
{
    char Spercentage[4];
    itoa(percentage, Spercentage, 10); // convert int to string

    sendSMS(Mobile_no, concatS(string, Spercentage));
}
const char *concatS(const char *string, char sPercentage[4])
{
    char *result = malloc(strlen(string) + strlen(sPercentage) + 1);
    strcpy(result, string);
    strcat(result, sPercentage);
    return result;
}

int oxygenTankPercentage()
{
	float x;
	int y;
	x=getOxygenTankPressure();
	y= (100-((300000-x)/3000));
    return y;
}
int checkPatientExpPresure()
{
	float kilopascal = get_pressure(2);
	return kilopascal; // return patient expiration pressure in kilopascal
}

int Set_Heart_Rate()
{
	return 80;
}

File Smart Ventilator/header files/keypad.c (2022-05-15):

/*
 * GccApplication2.c
 *
 * Created: 5/12/2022 11:27:58 PM
 * Author : Piyumanthi
 */ 
#define F_CPU 16000000UL
#include <avr/io.h>
#include<util/delay.h>
#include "LCD16x2_4bit.h"

char Keypad()
{
	
	PORTB=0b1111110;         // make first row 0
	if((PINB &(1<<PINB4))==0)
	{
		_delay_ms(3);
		return'1';
	}

	else if((PINB&(1<<PINB5))==0)
	{
		_delay_ms(3);
		return'2';
	}
	else if((PINB&(1<<PINB6))==0)
	{
		_delay_ms(3);
		return'3';
	}
	

	PORTB=0b1111101;   // make second row 0
	if((PINB &(1<<PINB4))==0)
	{
		_delay_ms(3);
		return'4';
	}
	else if((PINB&(1<<PINB5))==0)
	{
		_delay_ms(3);
		return'5';
	}
	else if((PINB&(1<<PINB6))==0)
	{
		_delay_ms(3);
		return'6';
	}
	

	PORTB=0b1111011;   // make third row 0
	if((PINB &(1<<PINB4))==0)
	{
		_delay_ms(3);
		return'7';
	}
	else if((PINB&(1<<PINB5))==0)
	{
		_delay_ms(3);
		return'8';
	}
	else if((PINB&(1<<PINB6))==0)
	{
		_delay_ms(3);
		return'9';
	}
	

	PORTB=0b1110111;   // make fourth row 0
	if((PINB &(1<<PINB4))==0)
	{
		_delay_ms(3);
		return'*';
	}
	else if((PINB&(1<<PINB5))==0)
	{
		_delay_ms(3);
		return'0';
	}
	else if((PINB&(1<<PINB6))==0)
	{
		_delay_ms(3);
		return'#';
	}
	

}

int main(void)
{
	unsigned char x;
	DDRB=0x0F;         //Make PB0 to PB3 = output and PB4 to PB6=input
	LCD_Init ();
	while(1)
	{
		PORTB =0xF0;   //Make all columns 1 and all rows 0.
		if(PINB!=0xF0)
		{
			x=Keypad();
			LCD_Char(x);
		}
		
	}
	return 0;
}

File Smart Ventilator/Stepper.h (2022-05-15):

 *
 * The sequence of control signals for 5 phase, 5 control wires is as follows:
 *
 * Step C0 C1 C2 C3 C4
 *    1  0  1  1  0  1
 *    2  0  1  0  0  1
 *    3  0  1  0  1  1
 *    4  0  1  0  1  0
 *    5  1  1  0  1  0
 *    6  1  0  0  1  0
 *    7  1  0  1  1  0
 *    8  1  0  1  0  0
 *    9  1  0  1  0  1
 *   10  0  0  1  0  1
 *
 * The sequence of control signals for 4 control wires is as follows:
 *
 * Step C0 C1 C2 C3
 *    1  1  0  1  0
 *    2  0  1  1  0
 *    3  0  1  0  1
 *    4  1  0  0  1
 *
 * The sequence of controls signals for 2 control wires is as follows
 * (columns C1 and C2 from above):
 *
 * Step C0 C1
 *    1  0  1
 *    2  1  1
 *    3  1  0
 *    4  0  0
 *
 * The circuits can be found at
 *
 * http://www.arduino.cc/en/Tutorial/Stepper
 */
#include "millis.h"
// ensure this library description is only included once
#ifndef Stepper_h
#define Stepper_h

// library interface description

  
   
    
    Stepper(int number_of_steps, int motor_pin_1, int motor_pin_2,
                                 int motor_pin_3, int motor_pin_4);
    

    // speed setter method:
    void setSpeed(long whatSpeed);

    // mover method:
    void step(int number_of_steps);

    int version(void);

    void stepMotor(int this_step);
	
struct  Stepper {
    int direction;            // Direction of rotation
    unsigned long step_delay; // delay between steps, in ms, based on speed
    int number_of_steps;      // total number of steps this motor can take
    int pin_count;            // how many pins are in use.
    int step_number;          // which step the motor is on

    // motor pin numbers:
	
    int motor_pin_1;
    int motor_pin_2;
    int motor_pin_3;
    int motor_pin_4;
    

    unsigned long last_step_time; // time stamp in us of when the last step was taken
	
};

void Stepper(int number_of_steps, int motor_pin_1, int motor_pin_2,
int motor_pin_3, int motor_pin_4)
{
	step_number = 0;    // which step the motor is on
	direction = 0;      // motor direction
	last_step_time = 0; // timestamp in us of the last step taken
	number_of_steps = number_of_steps; // total number of steps for this motor
	init_millis(8000000UL); //frequency the atmega328p is running at
	sei();
	// Arduino pins for the motor control connection:
	motor_pin_1 = DDRC | (1<<4);
	motor_pin_2 = DDRC | (1<<5);
	motor_pin_3 = DDRC | (1<<6);
	motor_pin_4 = DDRC | (1<<7);

	// setup the pins on the microcontroller:
	DDRC=motor_pin_1;
	DDRC=motor_pin_2;
	DDRC=motor_pin_3;
	DDRC=motor_pin_4;

	// When there are 4 pins, set the others to 0:
	

	// pin_count is used by the stepMotor() method:
	pin_count = 4;
}
void setSpeed(long whatSpeed)
{
	step_delay = 60L * 1000L * 1000L / number_of_steps / whatSpeed;
}

void step(int steps_to_move)
{
	int steps_left = abs(steps_to_move);  // how many steps to take

	// determine direction based on whether steps_to_mode is + or -:
	if (steps_to_move > 0) { direction = 1; }
	if (steps_to_move < 0) { direction = 0; }


	// decrement the number of steps, moving one step each time:
	while (steps_left > 0)
	{
		unsigned long now = millis()*1000;
		// move only if the appropriate delay has passed:
		if (now - last_step_time >= step_delay)
		{
			// get the timeStamp of when you stepped:
			last_step_time = now;
			// increment or decrement the step number,
			// depending on direction:
			if (direction == 1)
			{
				step_number++;
				if (step_number == number_of_steps) {
					step_number = 0;
				}
			}
			else
			{
				if (step_number == 0) {
					step_number = number_of_steps;
				}
				step_number--;
			}
			// decrement the steps left:
			steps_left--;
			// step the motor to step number 0, 1, ..., {3 or 10}
			if (pin_count == 5)
			stepMotor(step_number % 10);
			else
			stepMotor(step_number % 4);
		}
	}
}
void Stepper::stepMotor(int thisStep)
{
	if (this->pin_count == 4) {
		switch (thisStep) {
			case 0:  // 1010
			PORTC = PORTC | (1<<4);
			PORTC = PORTC | (1<<6);
			PORTC = PORTC | (1<<6);
			PORTC = PORTC | (1<<5);
			break;
			case 1:  // 0110
			PORTC = PORTC | (1<<4);
			PORTC = PORTC | (1<<6);
			PORTC = PORTC | (1<<4);
			PORTC = PORTC | (1<<6);
			break;
			case 2:  //0101
			PORTC = PORTC | (1<<4);
			PORTC = PORTC | (1<<5);
			PORTC = PORTC | (1<<5);
			PORTC = PORTC | (1<<6);
			break;
			case 3:  //1001
			PORTC = PORTC | (1<<4);
			PORTC = PORTC | (1<<6);
			PORTC = PORTC | (1<<5);
			PORTC = PORTC | (1<<4);
			break;
		}
	}
}

#endif

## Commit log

2021-12-03 update solenoid valve control
2021-12-05 update solenoid valve open
2022-05-13 Update solenoid valve
2022-05-14 update stepper motor
2022-05-15 stepper motor header added
2022-05-15 Timer Delay Added
2022-05-15 solenoid valve and stepper motor work simultaneously
2022-05-16 External Interrupt Added
2022-05-22 buttons added
2022-05-23 Power Supply Added
2022-05-24 Add Pressure and Temperature Sensor
2022-05-24 Change Pressure value
2022-06-07 GSM Code Updated
    [Smart Ventilator PCB.kicad_pcb, Smart Ventilator PCB.kicad_sch]
2022-06-08 PCB Added
    [Body Temperature.kicad_sch, Heart Rate & SPO2.kicad_sch, Power Supply.kicad_sch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]
